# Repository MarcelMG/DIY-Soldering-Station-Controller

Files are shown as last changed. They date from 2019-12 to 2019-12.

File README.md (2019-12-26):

# DIY-Soldering-Station-Controller
A soldering station controller compatible with [Weller RT active tips](https://www.weller-tools.com/professional/USA/us/Professional/Soldering+technology/Soldering+tips+_+nozzles/Soldering+tips/RT+Active+Tips)
The design is kept simple, with a rotary encoder with internal pushbutton to set the temperature and
a TM1637 4-digit 7-segment LED display. When the pushbutton is pressed for >3s, the current target temperature is stored as default value in the non-volatile EEPROM memory of the microcontroller. When the iron handle is put in the stand, the iron goes into standby mode and reduces it's temperature to 100°C. Originally I planned to use a hall sensor to detect the handle in the stand, but I chose a simpler solution by connencting an input pin of the microcontroller with internal pullup resistor to the stand. Since the metal part of the iron tip is grounded, it can sets the pin low and thus enables to detect the iron in the stand.
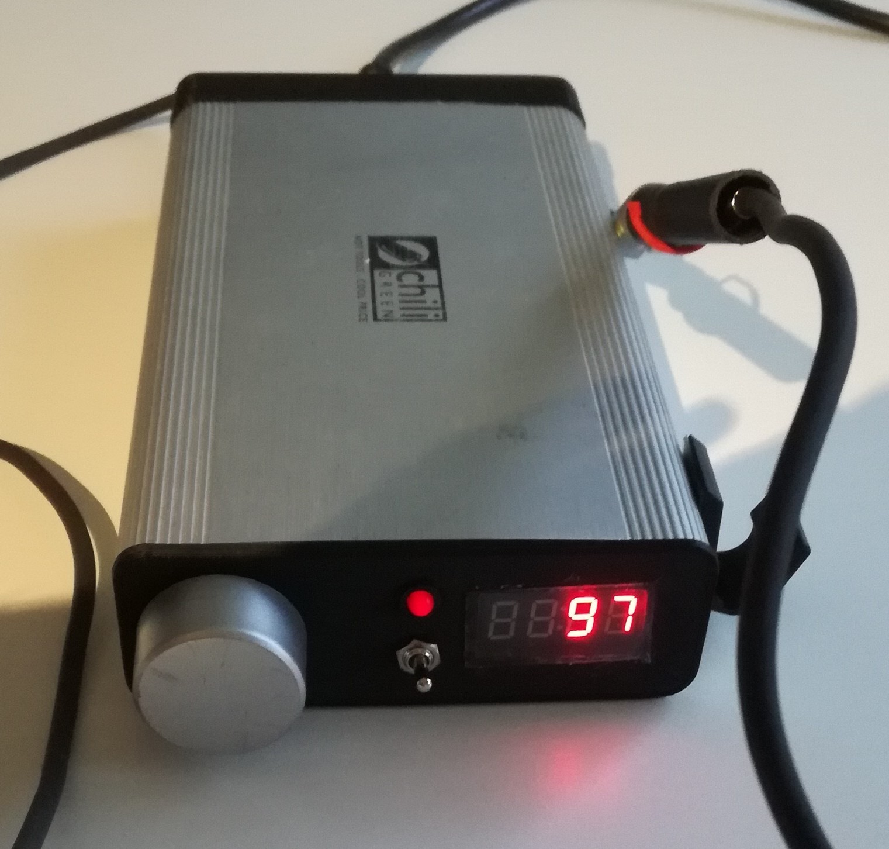
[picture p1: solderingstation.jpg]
solderingstation


The microcontroller used is a Microchip ATTiny24A. The program code just fits barely into the small flash memory (2kB), so a variant like the ATtiny44 (4kB) or 88 (8kB) might be more appropriate. The display is a TM1637 4-digit 7-segment LED display module, those can be found cheaply on ebay etc. One big advantage of these modules is, that they need only 2 GPIO pins to communicate with the display using an I²C-ish interface. The rotary encoder used has an internal pushbutton, the one I used is salvaged from an old radio. The power supply is a also salvaged from an old laptop or similar, it supplies 12V DC at something around 3.6A. The Weller RT tips are rated at 44W max., so a quite beefy power supply is needed. The Weller RT tips use a standard 3,5mm stereo audio jack connector with the following pinout:
* tip = heating element
* middle ring = thermocouple sensor
* sleeve (back ring) = GND

The thermocouple signal is amplified with a low input offset voltage rail-to-rail OpAmp and fed to the microcontrollers internal ADC. The µC's internal bandgap voltage reference is used. Two RC-lowpass filters in the signal path remove noise in the signal. It is important to only measure the thermocouple sensor voltage when the heating element is off, or else erroneous readings will be produced. To achieve this, the heater is controlled with a center-aligned (a.k.a. phase correct) PWM. In the middle of the low-cycle of the PWM, an interrupt triggers an AD-conversion. The PWM duty-cycle is computed with a P-controller to control the temperature. The heating element is switched with a p-MOSFET power transistor. To drive it's gate with 12V from the microcontrollers 5V level, another small nMOSFET is used. A PCB for the design has been designed and manufactured. The microcontroller is programmed via an 6-pin ISP connector.
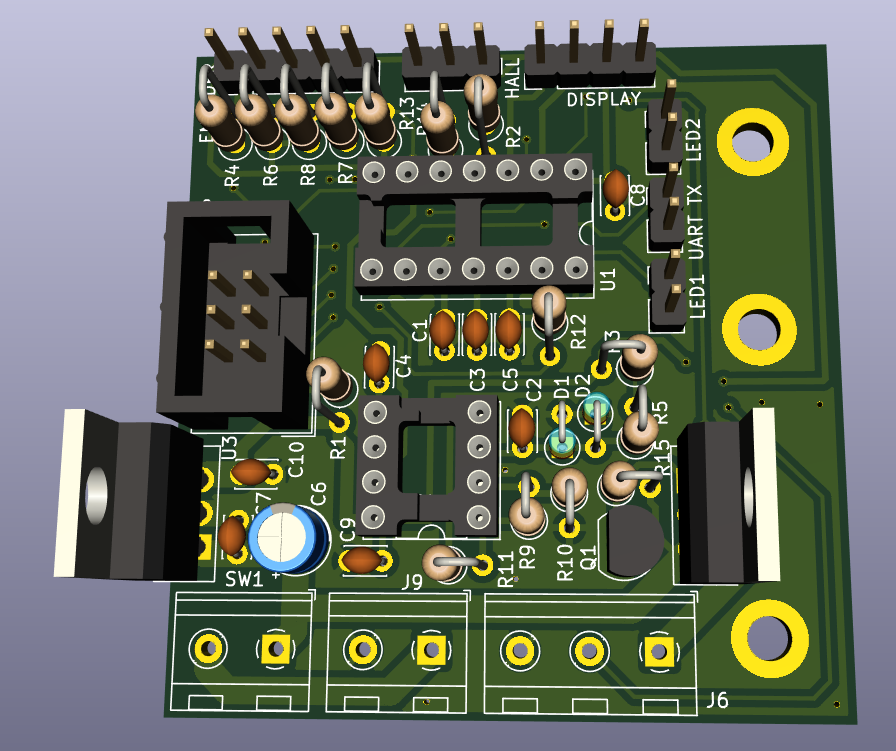
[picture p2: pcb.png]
pcb


This is the connection diagram (pinout) of the PCB:
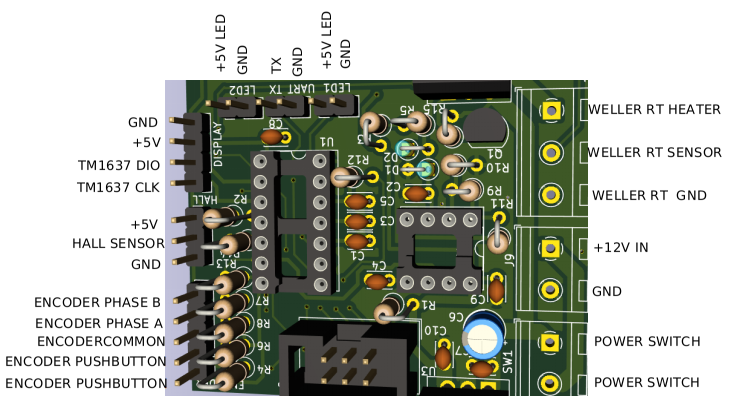
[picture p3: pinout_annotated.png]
pinout_annotated


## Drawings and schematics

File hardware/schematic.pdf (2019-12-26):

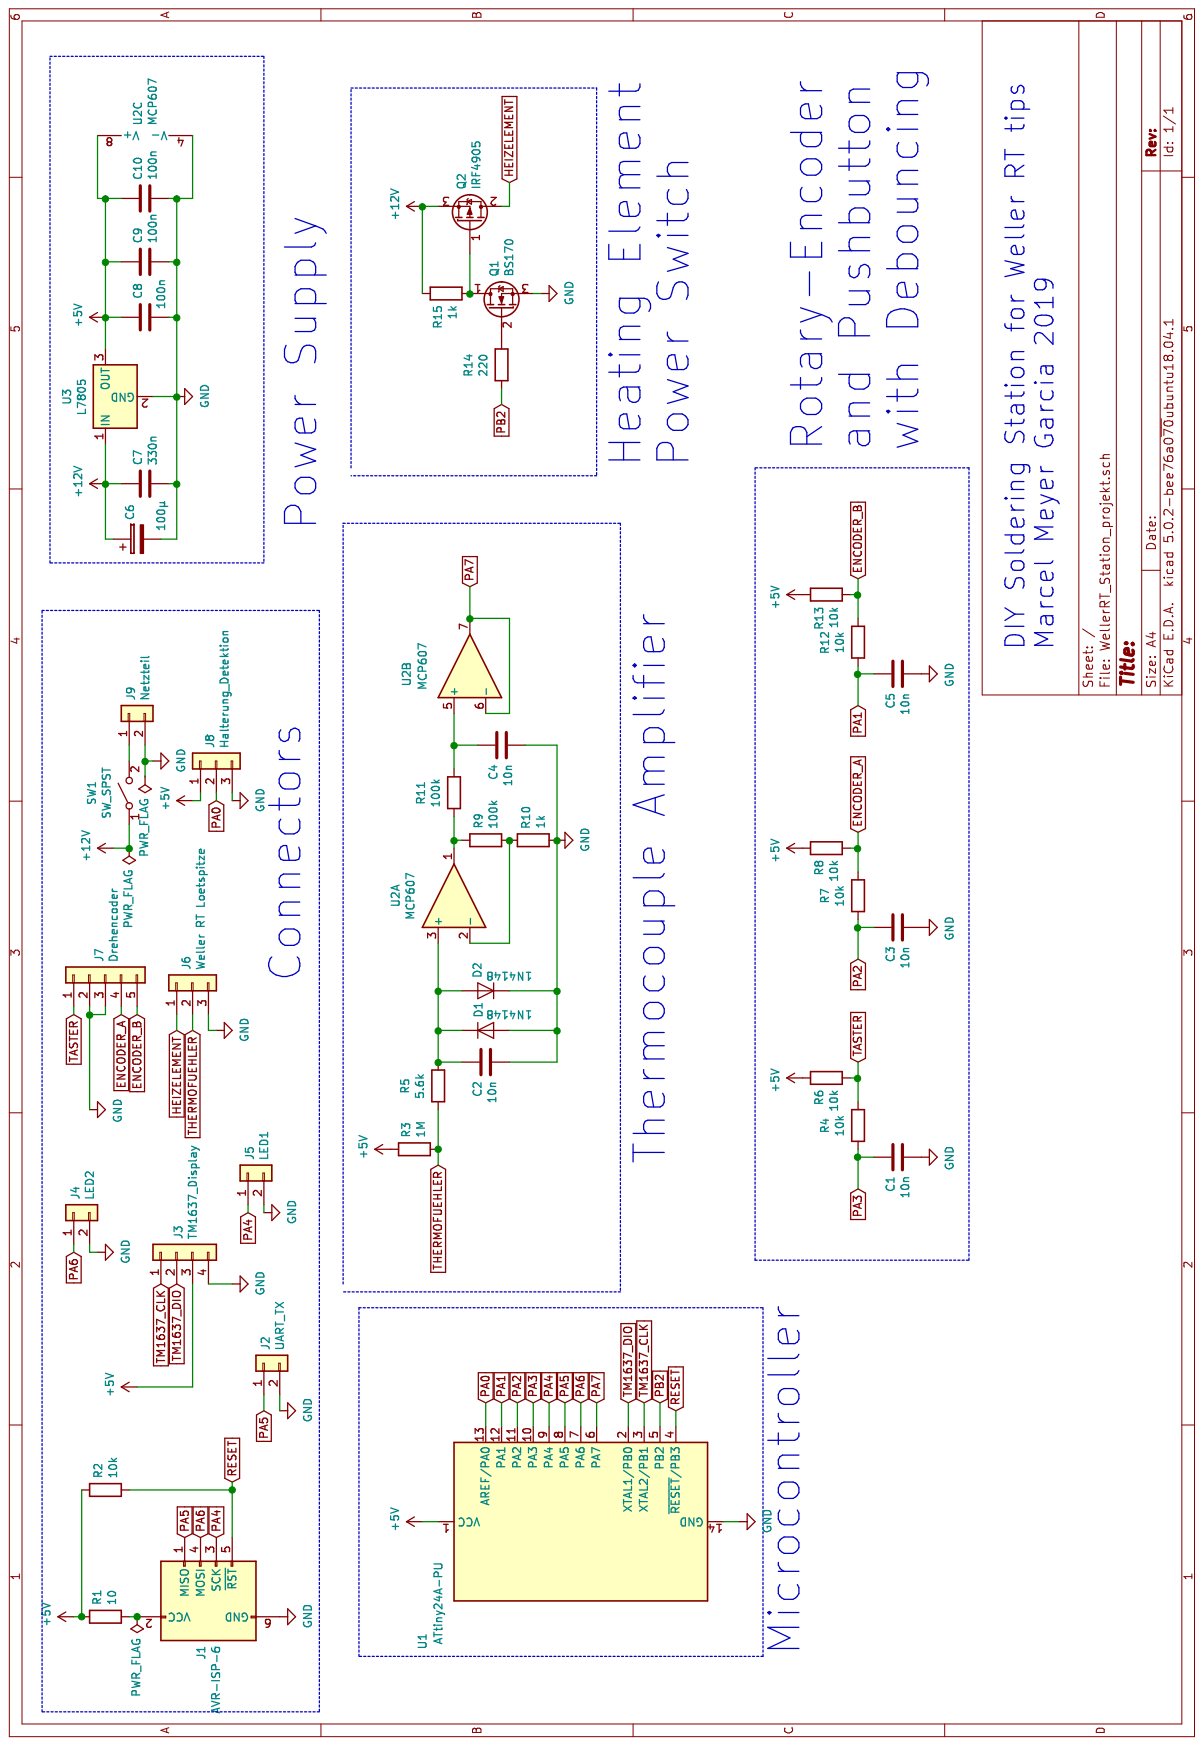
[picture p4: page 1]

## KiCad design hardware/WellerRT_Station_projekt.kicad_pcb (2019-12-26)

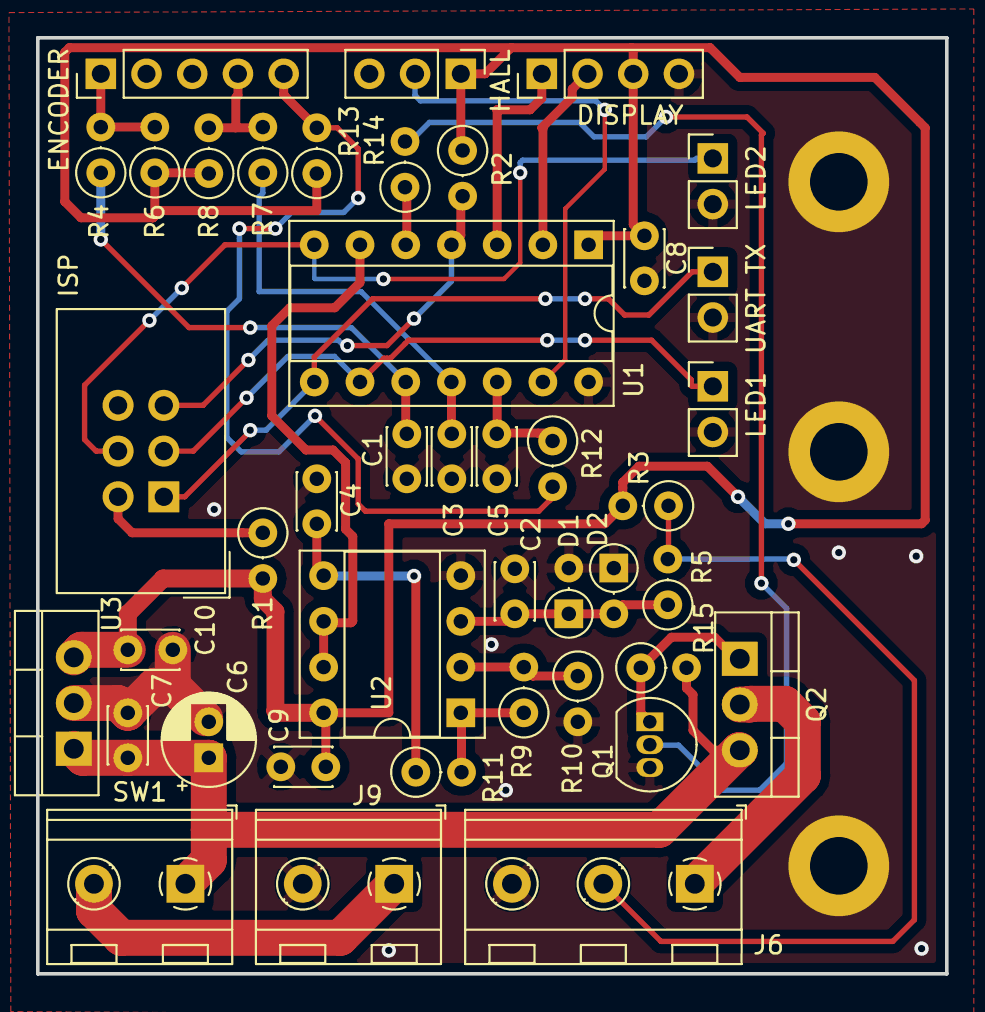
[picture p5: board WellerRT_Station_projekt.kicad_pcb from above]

Board: 2 copper layers, 50.5 x 52.0 mm, 45 parts (0 on the bottom side), 28 nets.

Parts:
 ~: MountingHole_3.2mm_M3_DIN965_Pad
 ~#2,  ~#3: MountingHole_3.2mm_M3_DIN965_Pad
C1, C2, C3, C4, C5: 10n; C_Disc_D3.0mm_W2.0mm_P2.50mm
C6: 100µ; CP_Radial_D5.0mm_P2.00mm
C7: 330n; C_Disc_D3.0mm_W2.0mm_P2.50mm
C8, C9, C10: 100n; C_Disc_D3.0mm_W2.0mm_P2.50mm
D1, D2: D; D_DO-35_SOD27_P2.54mm_Vertical_AnodeUp
DISPLAY: TM1637_Display; PinHeader_1x04_P2.54mm_Vertical
ENCODER: Drehencoder; PinHeader_1x05_P2.54mm_Vertical
HALL: Halterung_Detektion; PinHeader_1x03_P2.54mm_Vertical
ISP: AVR-ISP-6; IDC-Header_2x03_P2.54mm_Vertical
J6: Weller RT Loetspitze; TerminalBlock_RND_205-00233_1x03_P5.08mm_Horizontal
J9: Netzteil; TerminalBlock_RND_205-00232_1x02_P5.08mm_Horizontal
LED1: LED1; PinHeader_1x02_P2.54mm_Vertical
LED2: LED2; PinHeader_1x02_P2.54mm_Vertical
Q1: BS170; TO-92_Inline
Q2: IRF4905; TO-220-3_Vertical
R1: 10; R_Axial_DIN0207_L6.3mm_D2.5mm_P2.54mm_Vertical
R2, R4, R6, R7, R8, R12, R13: 10k; R_Axial_DIN0207_L6.3mm_D2.5mm_P2.54mm_Vertical
R3: 1M; R_Axial_DIN0207_L6.3mm_D2.5mm_P2.54mm_Vertical
R5: 5.6k; R_Axial_DIN0207_L6.3mm_D2.5mm_P2.54mm_Vertical
R9, R11: 100k; R_Axial_DIN0207_L6.3mm_D2.5mm_P2.54mm_Vertical
R10, R15: 1k; R_Axial_DIN0207_L6.3mm_D2.5mm_P2.54mm_Vertical
R14: 220; R_Axial_DIN0207_L6.3mm_D2.5mm_P2.54mm_Vertical
SW1: SW_SPST; TerminalBlock_RND_205-00232_1x02_P5.08mm_Horizontal
U1: ATtiny24A-PU; DIP-14_W7.62mm_Socket
U2: MCP607; DIP-8_W7.62mm_Socket
U3: L7805; TO-220-3_Vertical
UART TX: UART_TX; PinHeader_1x02_P2.54mm_Vertical

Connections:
+5V: C8.1, C9.1, C10.1, DISPLAY.3, HALL.1, R1.2, R2.1, R3.2, R6.1, R8.1, R13.1, U1.1, U2.8, U3.3
+12V: C6.1, C7.1, Q2.3, R15.2, SW1.1, U3.1
ENCODER_A: ENCODER.4, R7.2, R8.2
ENCODER_B: ENCODER.5, R12.2, R13.2
GND: ~.1, ~#2.1, ~#3.1, C1.2, C2.1, C3.2, C4.1, C5.2, C6.2, C7.2, C8.2, C9.2, C10.2, D1.2, D2.1, DISPLAY.4, ENCODER.2, ENCODER.3, HALL.3, ISP.6, J6.3, J9.2, LED1.2, LED2.2, Q1.3, R10.2, U1.14, U2.4, U3.2, UART TX.2
HEIZELEMENT: J6.1, Q2.2
unnamed: C2.2, D1.1, D2.2, R5.1, U2.3
unnamed: C4.2, R11.1, U2.5
unnamed: ISP.2, R1.1
unnamed: J9.1, SW1.2
unnamed: Q1.1, Q2.1, R15.1
unnamed: Q1.2, R14.2
unnamed: R9.2, R10.1, U2.2
unnamed: R9.1, R11.2, U2.1
PA0: HALL.2, U1.13
PA1: C5.1, R12.1, U1.12
PA2: C3.1, R7.1, U1.11
PA3: C1.1, R4.1, U1.10
PA4: ISP.3, LED1.1, U1.9
PA5: ISP.1, U1.8, UART TX.1
PA6: ISP.4, LED2.1, U1.7
PA7: U1.6, U2.6, U2.7
PB2: R14.1, U1.5
RESET: ISP.5, R2.2, U1.4
TASTER: ENCODER.1, R4.2, R6.2
THERMOFUEHLER: J6.2, R3.1, R5.2
TM1637_CLK: DISPLAY.1, U1.3
TM1637_DIO: DISPLAY.2, U1.2

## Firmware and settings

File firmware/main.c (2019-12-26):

/*	Soldering Station Controller
 *	main program
 *  written in 2019 by Marcel Meyer-Garcia
 *  see LICENCE.txt
 */

#define MAX_TEMPERATURE 450
#define STANDBY_TEMPERATURE 100
/* P-Controller factor is P = MULTIPLIER/(2^BITSHIFT) e.g. P = 3/(2^1)=3/2=1.5 */
#define P_CONTROLLER_GAIN_MULTIPLIER 3
#define P_CONTROLLER_GAIN_BITSHIFT 1
#define DISPLAY_REFRESH_MS 300
#define DISPLAY_TIME_TARGET_TEMP 500
#define PUSHBUTTON_SAVE_TEMPERATURE_MS 1000

#include <stdlib.h>
#include <util/delay.h>
#include <avr/eeprom.h>
//#include "soft_uart.h"
#include "adc.h"
#include "encoder.h"
#include "tm1637.h"
#include "pwm.h"
#include "misc.h"
#include "time.h"

/* EEPROM variable */
uint16_t EEMEM default_temperature = 25;

int main(void)
{
	/* variable declaration */
	uint16_t target_temperature = 0;
	uint16_t current_temperature = 0;
	uint8_t duty_cycle = 0;
	uint32_t last_display_refresh_time = 0;
	uint32_t last_encoder_change_time = 0;
	
	setup_time(); // system time in µs and ms
	setup_adc(); // setup ADC for thermocouple readout
	//soft_uart_setup(); // software UART TX for debugging (optional)
	TM1637_init(1, 3); // initialize display with brightness level 3 (0..7)
	TM1637_display_colon(false); // dont't display colon between 2nd and 3rd digit
	setup_pwm(); // setup PWM for heater control
	pwm_set_duty_cycle(0); // turn off heater
	init_standby_sensor(); // set pin for standby-detection sensor as input with pullup
	init_led1(); // set LED1 pin as output
	
	// read default temperature from EEPROM
	eeprom_busy_wait();
	target_temperature = eeprom_read_word(&default_temperature);
	// value sanity check
	target_temperature = ulimit(target_temperature, 0, MAX_TEMPERATURE);
	// setup encoder knob, initialize enconder count i.e. target temperature with default value from EEPROM
	encoder_setup(target_temperature);
	display_temperature(target_temperature);
	_delay_ms(500);
	
	while (1){
		
		// check if it's time to perform a AD-conversion (when the PWM output is low, i.e. the heater turned off)
		if( new_adc_reading_ready == true ){
			new_adc_reading_ready = false; // clear flag
			// this readings take about 945µs (timed with oscilloscope), 2^4=16 samples, 52µs per AD-conversion plus CPU cycles for calculations
			current_temperature = adc2celsius(adc_read_average(4));
			// P-controller to control the soldering iron temperature
			if( current_temperature >= target_temperature ){
				duty_cycle = 0; // turn heater off
			}else{ // if( current_temperature < target_temperature )
				// note: we need a temporary 16bit variable to perform the computation
				uint16_t tmp_duty_cycle = target_temperature - current_temperature; // compute difference
				// apply gain factor without using floating-point math by first multiplying a factor, then dividing by 2^N
				tmp_duty_cycle *= P_CONTROLLER_GAIN_MULTIPLIER;
				tmp_duty_cycle = (tmp_duty_cycle>>P_CONTROLLER_GAIN_BITSHIFT); // do right bit-shift instead of division, equivalent to tmp_duty_cycle=tmp_duty_cycle/(2^P_CONTROLLER_GAIN_BITSHIFT)
				// limit duty-cycle
				tmp_duty_cycle = ulimit(tmp_duty_cycle, 0, MAX_PWM);
				duty_cycle = (uint8_t) tmp_duty_cycle;
			}
			pwm_set_duty_cycle(duty_cycle); // apply new computed duty-cycle
		}
		

		
		// check if iron is in stand (standby mode)
		if( read_standby_sensor() == STANDBY_SENSOR_STANDBY ){
			target_temperature = STANDBY_TEMPERATURE;
			set_led1(true);
		}else{
			// read target temperature from encoder knob, limit value
			uint16_t encoder_count_local = (uint16_t) limit(get_encoder_count(), 0, MAX_TEMPERATURE);
			// check if the encoder knob has been turned since the last time we checked and if yes, save the time
			if( encoder_count_local != target_temperature ){
				last_encoder_change_time = get_time_ms();
			}
			// set encoder value as target temperature
			target_temperature = (uint16_t) limit(get_encoder_count(), 0, MAX_TEMPERATURE);
			set_encoder_count((int16_t) target_temperature); // limit encoder count		
			set_led1(false);	
		}
		
		// if we the encoder hasn't been turned recently (e.g. in the last 1s), show current temperature, else show target temperature
		if( ( get_time_ms() - last_encoder_change_time ) < DISPLAY_TIME_TARGET_TEMP ){
			// refresh display instantly, show target temperature
			display_temperature(target_temperature);
		}else if( (get_time_ms() - last_display_refresh_time) > DISPLAY_REFRESH_MS ){
			// show current temperature, but refresh display only from time to time (e.g. every 100ms) to avoid flickering of the last digit
			display_temperature(current_temperature);
			last_display_refresh_time = get_time_ms();
		}

		if( get_encoder_button_state() == BUTTON_PRESSED ){
			pwm_set_duty_cycle(0); // turn heater off
			uint32_t t = get_time_ms();
			while(get_encoder_button_state() == BUTTON_PRESSED){
				// if button has been pressed for longer than a certain time
				if( (get_time_ms() - t) >= PUSHBUTTON_SAVE_TEMPERATURE_MS ){
					TM1637_clear(); // clear display
					// save current target temperature as default temperature in non-volatile EEPROM
					eeprom_busy_wait();
					eeprom_write_word(&default_temperature, target_temperature);
					display_okay();
					_delay_ms(2000);
					break;
				}
			}
			pwm_set_duty_cycle(duty_cycle); // turn heater on again
		}

    }
}

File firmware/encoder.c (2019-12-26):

/*	library for rotary-encoder with integrated pushbutton
 *	part of Soldering Station project
 *  written in 2019 by Marcel Meyer-Garcia
 *  see LICENCE.txt
 */
#include "encoder.h"
#include "time.h"

volatile bool encoder_button_state;
volatile int8_t encoder_last_state = 0;
volatile int16_t encoder_counter = 0;
volatile bool encoder_button_state = 0; // 0==button released, 1==button pressed

ISR(PCINT0_vect){
	// read encoder state
	// convert 2bit gray-code to binary
	/*	A B  binary
		----------
		0 0 | 00 (0)
		1 0 | 11 (3)
		1 1 | 10 (2)
		0 1 | 01 (1)	*/
	int8_t encoder_state = 0;
	if( PINA & (1<<PINA1) ) encoder_state = 0b11;
	if( PINA & (1<<PINA2) ) encoder_state ^= 0b01;
	if( (encoder_state - encoder_last_state) != 0 ){
	/*	the difference of current and last encoder state can be
		1 (0b00000001) or -3 (0b11111101) (2-complement) for one direction of rotation or
		-1 (0b11111111) (2-complement) or 3 (0b00000011) for the other direction
		we can see that the 2nd LSB gives the direction in which the encoder was turned
	*/
	if( (encoder_state - encoder_last_state) & 0b10 ) ++encoder_counter;
	else --encoder_counter;
	}
	encoder_last_state = encoder_state;
	/* check button state */
	// riding edge->button released ; falling edge->button pressed
	encoder_button_state = !(PINA & (1<<PINA3));
}

void encoder_setup(int16_t encoder_counter_start){
	// initialize encoder counter
	encoder_counter = encoder_counter_start;
	// pins PA1, PA2 and PA3 as inputs without pull-ups
	DDRA &=~((1<<DDA3)|(1<<DDA2)|(1<<DDA1));
	PORTA &=~((1<<PORTA3)|(1<<PORTA2)|(1<<PORTA1));
	// enable pin change interrupt on pins PCINT0..7
	GIMSK |= (1<<PCIE0);
	// unmask pin change interrupt for pins PA1(PCI1), PA2(PCI2) and PA3(PCI3)
	PCMSK0 |= (1<<PCINT3)|(1<<PCINT2)|(1<<PCINT1);
	// initialize encoder state
	// convert 2bit gray-code to binary
	encoder_last_state = 0;
	if( PINA & (1<<PINA1) ) encoder_last_state = 0b11;
	if( PINA & (1<<PINA2) ) encoder_last_state ^= 0b01;
	// globally enable interrupts
	sei();
}

int16_t get_encoder_count(){
	// disable pin change interupt 0 (so variable doesn't change if interrupt occurs while reading it)
	GIMSK &=~(1<<PCIE0);
	int16_t encoder_count = encoder_counter;
	// re-enable pin change interupt 0
	GIMSK |= (1<<PCIE0);
	return encoder_count;
}

void set_encoder_count(int16_t count){
	// disable pin change interupt 0 (so variable doesn't change if interrupt occurs while reading it)
	GIMSK &=~(1<<PCIE0);
	encoder_counter = count;
	// re-enable pin change interupt 0
	GIMSK |= (1<<PCIE0);
}

// returns true if button is pressed
bool get_encoder_button_state(){
	// disable pin change interrupt 0 (so variable doesn't change if interrupt occurs while reading it)
	GIMSK &=~(1<<PCIE0);
	bool button_pressed = encoder_button_state;
	// re-enable pin change interrupt 0
	GIMSK |= (1<<PCIE0);
	return button_pressed;
}
